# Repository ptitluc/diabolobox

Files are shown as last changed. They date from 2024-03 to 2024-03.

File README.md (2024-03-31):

# Diabolobox



Diabolobox is an [OpenSCAD](https://openscad.org/) box building library with 3D printing in mind.

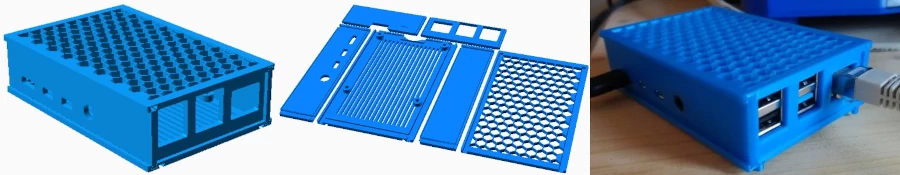
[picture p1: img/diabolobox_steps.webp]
three pictures illustrating a raspberry pi case design and printed result pimped diabolobox : a Raspberry Pi case


* **no screw, no glue** needed !
* **flat printing** makes it easy to print and allows **complex** and **neat cuts** on any face of the box.
* **strong joints** with the dovetail-like diabolo shape.
* **scales very well** since everything is parametric. Want a micro box or a huge one ? You got it.
* **easy customization** through the OpenSCAD customizer and the panels modules.

## Built-ins
* the box has a **self-locking lid**.
* ready to use optional **vents** are available. Just diff them with the panel :
   ```openscad
   diabolize_lr("right")
   difference() {
     db_panel("left_right");
	 vents();
    }
	```	
* handy optional **feets**.
* optional **pillars** for printed circuit boards.

## How it works
A box is a set of six panels which are connected together with rails and slides.

The connector shape is a variation around the good old [dovetail joint](https://en.wikipedia.org/wiki/Dovetail_joint) (but it looks more like a diabolo, hence the name. Amazing, isn't it ?).

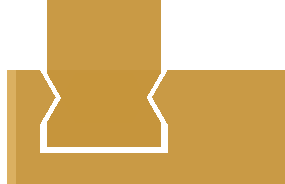
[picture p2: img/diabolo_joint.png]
detailed view of the diabolo joint the diabolo joint


To get an easy print, the width of the rails matches the thickness of a panel. 

All dimensions are calculated from inner or outer dimensions of the finished box.

Each panel is generated individually and can be customized. 
A built-in assembled view is available to adjust settings in a visual and easy way.

## Installation
Just clone this repository to a [location](https://en.wikibooks.org/wiki/OpenSCAD_User_Manual/Libraries) where OpenSCAD will find it.
## Usage
Include the library in your work by using the well named `include` statement :
```openscad
include <diabolobox/diabolobox.scad>;
```
### Basic usage
To get a nice 42 x 84 x 21 box, just use the following code :

```openscad
include <diabolobox/diabolobox.scad>;

width = 42;      // size along X axis
depth = 84;      // size along Y axish
height = 21;     // size along Z axis
thickness = 3;   // panel thickness
flat = true;     // toggle between print-ready and assembled 3D view

plain_box();
```

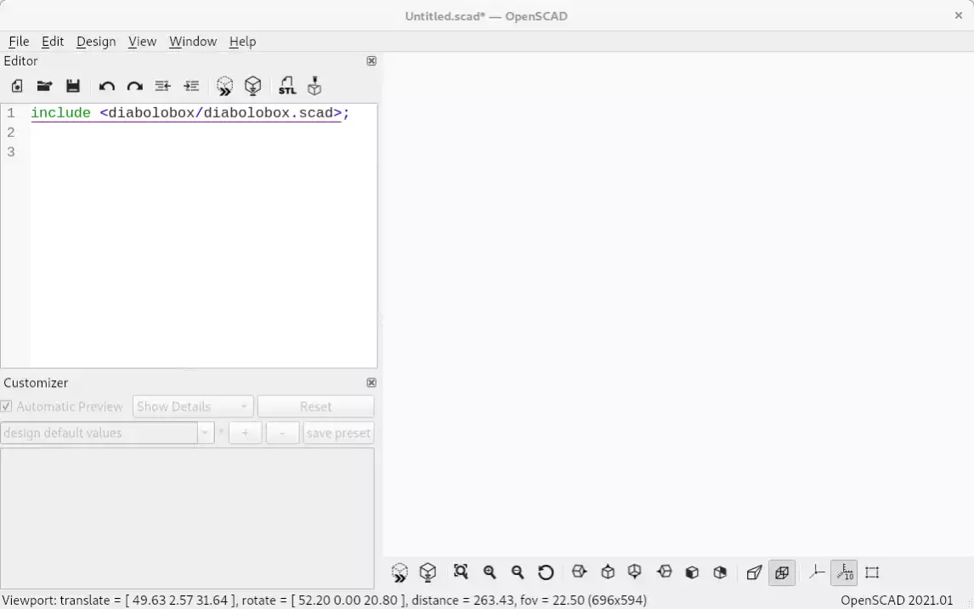
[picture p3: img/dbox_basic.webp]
capture of build a simple box in OpenSCAD


Here are some other variables you can use:
```openscad
edge_offset   = 1.5;   // left/right panel offset for top and bottom edges
corner_radius = 1;     // rounded top and bottom angle. 0 to disable.
fit_clearance = 0.3;   // assembly tighteness
inner_dim     = true;  // are width, depth and height outer or inner lengths ?
```

### Advanced usage
You can of course have far more control on the box customization.

You can generate a blank panel with the `db_panel` module. 
A blank panel does not have the diabolo joint system attached to it. Why not ? Because this is a convenient way to add or substract volume to the panel without bother with calculating offset due to the diabolo and rails.

The connectors are added by applying a `diabolize_xx` module to the panel.

here is a example on how to cut circle in the middle of a side panel :

```openscad
diabolize_lr("left")
difference() {
  db_panel("left_right");
  translate([od/2, ih/2, -0.01]) cylinder(d=2, h=th+0.02);
}
```
`od`, `ih` and `th` are variables you can use in your code.
They respectively stand for `outer depth`, `inner height` and `thickness`.

There some other variables like this, please refer to [the source code](diabolobox.scad) to get the list and usage. 

## Projects using diabolobox

I would be glad to add more projects here, feel free to add your own by editing this file and make a pull request.
* **[Diabolopi](https://github.com/ptitluc/diabolopi/)**: parametric Raspberry Pi cases.

## Contributing
 
The code is under GPLv3, fork it, modify it, use it, make pull requests and create issues !

## License
This is [GPLv3](https://www.gnu.org/licenses/gpl-3.0), please read the [LICENSE file](LICENSE).

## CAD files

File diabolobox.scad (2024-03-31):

/*
This file is part of Diabolobox - a library to design 3D printable boxes.
Copyright (C) 2024  Luc Milland

Diabolobox is free software: you can redistribute it and/or
modify it under the terms of the GNU General Public License
as published by the Free Software Foundation, either version 3
of the License, or (at your option) any later version.

Diabolobox is distributed in the hope that it will be useful, 
but WITHOUT ANY WARRANTY; without even the implied warranty of
MERCHANTABILITY or FITNESS FOR A PARTICULAR PURPOSE. See the 
GNU General Public License for more details.

You should have received a copy of the GNU General Public License
along with Diabolobox. If not, see <https://www.gnu.org/licenses/>
*/

use <utils/diabolo.scad>;
use <utils/rsquare.scad>;
use <utils/hexmap.scad>;

// ###########################################################################
//                      BOX DIMENSIONS AND PARAMETERS
//  just copy the following variables in your code to override values.
// ###########################################################################
width         = 19;    // length on X axis
depth         = 34;    // length on Y axis
height        = 11;    // length on Z axis
thickness     = 2.4;   // panel thickness
edge_offset   = 1.5;   // left/right panel offset for top and bottom edges
corner_radius = 1;     // rounded top and bottom angle. 0 to disable.
fit_clearance = 0.3;     // assembly tighteness
inner_dim     = true;  // are width, depth and height outer or inner lengths ?

//// display variables
/* [View] */
flat = false;  
show_lid = true;
show_left = true;
show_right = true;
show_back = true;
show_front = true;
show_bottom = true;
show_feet = true;
show_board = true;
explode_distance = 0.0; // [0:0.5:20]
/* [Color] */
red = 1;      // [0:0.01:1]
green = 0.75; // [0:0.01:1]
blue = 0.18;  // [0:0.01:1]
alpha = 1;    // [0:0.01:1]

module __customizer_limit__() {};

// ###########################################################################
//                              OTHER VARIABLES
//        some attempt to keep the core code but still readable
// ###########################################################################
$fn=64; // we want nice rounded shapes, don't we ?

// variable shortcuts
inner  = inner_dim; 
th     = thickness;
e_off  = edge_offset; 
cr     = corner_radius; 
fc     = fit_clearance; 

// calculated variables
off = th + e_off + fc/2; // outer to inner dimension offset
ow  = inner_dim == true ? width + 2 * off : width;  // outer width
iw  = inner_dim == true ? width : width - 2 * off;  // inner width
od  = inner_dim == true ? depth + 2 * off : depth;  // outer depth
id  = inner_dim == true ? depth : depth - 2 * off;  // inner depth
oh  = inner_dim == true ? height + 2 * th : height; // outer height
ih  = inner_dim == true ? height : height - 2 * th; // inner height
dh  = diabolo_height(th);
sw = th + fc;            // slide width
sh = diabolo_height(sw); // slide height
fc_comp = (dt_height(sw) - dt_height(th))/2; // compensate fit clearance


// ###########################################################################
//                              CORE MODULES                 
//   * db_panel : get a blank panel
//   * diabolize_bt : add rails and slide to a top or bottom panel
//   * diabolize_lr : add rails and slide to a left or right panel
//   * diabolize_fb : add rails and slide to a front or back panel
// ###########################################################################

// ***************************************************************************
//              db_panel("top_bottom"|"left_right"|"front_back")
// ***************************************************************************
// get a blank panel before applying a diabolize_xx module.
//
// remember that all dimensions apply to a flat panel :
//  * width or depth of box -> x axis 
//  * height of box -> y axis 
//  * panel thickness -> z axis
//
// Useful to apply transformations with simple coordinates.
// Example, to add a 2mm hole in the middle of the left panel and add the
// diabolobox joint system :
//
// diabolize_lr("left")
// difference() {
//   db_panel("left_right");
//   translate([od/2, ih/2, -0.01]) cylinder(d=2, h=th+0.02);
// }
// ***************************************************************************
module db_panel(panel) {
  if (panel == "top_bottom") {
    linear_extrude(th) rsquare([ow, od], cr, center=false);
  }
  else {
    // front/back or left/right panel
    size = panel == "front_back" ? [iw, ih] : [od, ih];   
    linear_extrude(th) square(size);
  }
}

// ***************************************************************************
//                 diabolize_bt(bottom=true|false)
// ***************************************************************************
// add the diabolobox joint system to a top or bottom panel.
//
// bottom got additionnal slides for back and front panels.
// top is a lid, so :
//   * slides are looser
//   * slides are shorter
//   * a lock bit is added
// ***************************************************************************
module diabolize_bt(bottom=true) {
              //     left/right slides positions
              //|    X     |     Y     |      Z       |
  l_slide_pos = [  e_off   ,  -0.01    , th - sh + 0.01];
  r_slide_pos = [ow - e_off, od + 0.01 , th - sh + 0.01];
  //                front/back slides positions
  //            |    Y      |     X       |         Z          |
  f_slide_pos = [-e_off - sw, e_off + sw/2, 2 * th/3 - fc + 0.01];
  b_slide_pos = [-od + e_off, e_off + sw/2, 2 * th/3 - fc + 0.01];

  slide_width = bottom == true ? sw : sw + 0.2;  // +0.2 clearance for lid
  difference() {
    children(0);
    lid_height_comp = bottom == true ? [0, 0, 0] : [0, 0, diabolo_height(0.2)];
    lid_side_comp = bottom == true ? [0, 0, 0] : [0.1, 0, 0];
    y_right_off = bottom == true ? [0, 0, 0] : [0, th, 0];
    l_pos = l_slide_pos - lid_height_comp - lid_side_comp;
    r_pos = r_slide_pos - lid_height_comp + lid_side_comp - y_right_off;
    length = bottom == true ? od : od - th;
    // left slide
    translate(l_pos)
      diabolo(slide_width, length + 0.02, "bottom");
    // right slide
    translate(r_pos)
      rotate([0, 0,180])
      diabolo(slide_width, length + 0.02, "bottom");
    // front and back slides
    if (bottom==true) {
      rotate([0, 0, -90])
	translate(f_slide_pos)
	cube([sw, iw + sw, th/3 + fc]);
      rotate([0, 0, -90])
	translate(b_slide_pos)
	cube([sw, iw + sw, th/3 + fc]);
    }
  }
  if (bottom==false) {
    // blocker bit in the lid
    blocker_off = od - e_off - 1.5 * sw;
    translate([e_off + sw + sw/10, blocker_off, th - sh])
      cylinder(d=sw/2, h=dh);
  }
}

// ***************************************************************************
//                     diabolize_lr("left"|"right")
// ***************************************************************************
// add the diabolobox joint system to a left or right panel.
//
// A right panel has a the blocker hole for the lid to snap in place.
// ***************************************************************************
module diabolize_lr(side) {
  translate([0, dh, 0])
    difference () {
      union() {
	children(0);
	stop = side == "left" ? th : 0;
	// top diabolo
	translate([0, ih , 0])
	  cube([od, fc_comp, th]);
	rotate([0, 0, -90])
	translate([-ih -dh - fc_comp, stop, 0])
	difference() {
	  diabolo(th, od - th, "left");
	  if (side == "right") {
	    blockhole_off = od - e_off - 1.5 * sw;
	    translate([-0.01, blockhole_off, + sw/11])
	      rotate([0, 90, 0])
	      cylinder(d=sw/2, h=dh);
	  }
	}
	// bottom diabolo
	rotate([0, 0, -90])
	  translate([fc_comp, 0, 0])
	  diabolo(th, od, "right");
	translate([0, -fc_comp, 0])
	  cube([od, fc_comp, th]);
      }
      // back slide
      rotate([0, 90, 0])
	translate([-sh + 0.01, -dh - 0.01 - fc_comp, e_off])
	diabolo(sw, ih + 2*(fc_comp + dh) + 0.02, "left");
      // front slide
      rotate([0, 90, 0])
	translate([-sh + 0.01, -dh - 0.01 - fc_comp, od - sw - e_off])
	diabolo(sw, ih + 2*(fc_comp + dh) + 0.02, "left");
    }
}
// ***************************************************************************
//                     diabolize_fb()
// ***************************************************************************
// add the diabolobox joint system to a front or back panel.
//
// both are strictly the same
// ***************************************************************************
module diabolize_fb() {   
    height = ih + th/3;
    translate([dh, 0, 0]) cube([iw, th/3, th]);
    translate([dh, th/3, 0]) children(0);
    translate([-fc_comp, 0, 0]) diabolo(th, height, "left");
    translate([dh - fc_comp, 0, 0]) cube([fc_comp, height, th]);
    translate([iw + dh, 0, 0])  cube([fc_comp, height, th]);
    translate([iw + dh + fc_comp, 0, 0]) diabolo(th, height, "right");
}
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

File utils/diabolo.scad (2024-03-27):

/*
This file is part of Diabolobox - a library to design 3D printable boxes.
Copyright (C) 2024  Luc Milland

Diabolobox is free software: you can redistribute it and/or
modify it under the terms of the GNU General Public License
as published by the Free Software Foundation, either version 3
of the License, or (at your option) any later version.

Diabolobox is distributed in the hope that it will be useful, 
but WITHOUT ANY WARRANTY; without even the implied warranty of
MERCHANTABILITY or FITNESS FOR A PARTICULAR PURPOSE. See the 
GNU General Public License for more details.

You should have received a copy of the GNU General Public License
along with Diabolobox. If not, see <https://www.gnu.org/licenses/>
*/

a = 60; // dovetail angle
function dt_height(width) = width * tan(a)/4;
function dt_top_width(width) = 2*dt_height(width)/tan(a);
function diabolo_height(width) = dt_height(width)*1.5;
  
module dove_tail(width, depth) {
  x1 = width;
  h = dt_height(width);
  x2 = dt_top_width(width);
  
  translate([0, depth, 0])
  rotate([90, 0, 0]) 
  linear_extrude(depth)
  hull() {
    square([x1, 0.001]);
    translate([(x1-x2)/2, h]) square([x2, 0.001]);
  }      
}

module position(position, width) {
                          //           rotation     translation   
  transform = position == "left"   ? [[0, 90, 0],  [0, 0, width]] :
              position == "top"    ? [[0, 180, 0], [width, 0, diabolo_height(width)]] :
              position == "right"  ? [[0, -90, 0], [diabolo_height(width), 0, 0]] :
              position == "bottom" ? [[0, 0, 0],   [0, 0, 0]] : undef;
  assert(!is_undef(transform), str("position as to be 'left', 'top', 'right' or 'bottom'"));
  translate(transform[1]) rotate(transform[0]) children();
}

module __diabolo(width, depth) {
  dth = dt_height(width);
   translate([0, 0, dth/2]) {
     dove_tail(width, depth);
     translate([0, 0, dth]) mirror([0, 0, 1]) dove_tail(width, depth);
     translate([0, 0, -dth/2]) mirror([0, 0, 0]) cube([width, depth, dth/2]);
   }
}

module diabolo(width, depth, position) {
  position(position, width)  __diabolo(width, depth);
}

diabolo(7, 15, "bottom");

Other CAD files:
utils/hexmap.scad
utils/rsquare.scad
db_demo.scad

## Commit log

2024-03-27 Hello, World of Boxes!
    [db_demo.scad, diabolo.scad, diabolobox.scad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]
2024-03-28 fix bad default fit clearance
    [diabolobox.scad]
2024-03-28 feature: add `plain_box` module
    [diabolobox.scad]
2024-03-31 Readme: no screw, no glue !
2024-03-31 feet and feet slot need to be smaller
    else it is to thin and there is small holes when
    printing at 0.2 mm layer height.
    [diabolobox.scad]

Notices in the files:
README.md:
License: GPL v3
